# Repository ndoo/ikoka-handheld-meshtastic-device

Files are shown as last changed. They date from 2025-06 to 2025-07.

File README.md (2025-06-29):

# Ikoka Stick Meshtastic Device

## Ikoka! (行こか!)

“行こか?” or “行こか!” is [Kansai dialect](https://en.wikipedia.org/wiki/Kansai_dialect) for “shall we go?” or “let’s go!”.

I hope that building these long-range Meshtastic designs inspires you to go on your next [DXing](https://en.wikipedia.org/wiki/DXing) adventure.

## Features

- LoRa
  - Up to 33 dBm (2 W) output power
  - 410–493 MHz (433 MHz band) or 850–930 MHz (868/915/923 MHz band)
- Bluetooth 5 LE
- Lithium-ion battery with charging
- 0.96" OLED display

Feature set above depends on part selection.

### Hardware

### Parts Selection

Several options are available depending on the feature set you need.

#### Microcontroller

- [Seeed Studio XIAO-nRF52840](https://www.seeedstudio.com/Seeed-XIAO-BLE-nRF52840-p-5201.html) - Bluetooth 5/LE
- [Seeed Studio XIAO-ESP32-S3](https://www.seeedstudio.com/XIAO-ESP32S3-p-5627.html) - Bluetooth 5/LE and Wi-Fi 4 (2.4 GHz)

#### LoRa Module

- [E22-400M22S](https://www.cdebyte.com/products/E22-400M22S) (410–493 MHz at 22 dBm)
- [E22-400M30S](https://www.cdebyte.com/products/E22-400M30S) (410–493 MHz at 30 dBm)
- [E22-400M33S](https://www.cdebyte.com/products/E22-400M33S) (410–493 MHz at 33 dBm)
- [E22-900M22S](https://www.cdebyte.com/products/E22-900M22S) (850–930 MHz at 22 dBm)
- [E22-900M30S](https://www.cdebyte.com/products/E22-900M30S) (850–930 MHz at 30 dBm)
- [E22-900M33S](https://www.cdebyte.com/products/E22-900M33S) (850–930 MHz at 33 dBm)

#### Lithium-ion Battery (4.2V charging termination, optional)

- Lithium-polymer pouch battery cell (4.2V charge termination; connector: Molex PicoBlade 1x02P, pitch 1.25mm)

#### OLED Display (Optional)

- Generic SSD1306 0.96" OLED display modules with FPC connector ([Vishay OLED-128O064D-BPP3N00000](https://www.vishay.com/en/product/37902/) or generic OLEDs with the same connector dimensions and pinout)

## Firmware

### GPIO Assignment

| XIAO Pin | Function | XIAO-nRF52840 | XIAO-ESP32-S3 |
|---|---|---|---|
| 1 (D0) | User button | 2 (P0.02) | 1 |
| 2 (D1) | EBYTE E22 - DIO1 | 3 (P0.03) | 2 |
| 3 (D2) | EBYTE E22 - RST | 28 (P0.28) | 3 |
| 4 (D3) | EBYTE E22 - BUSY | 29 (P0.29) | 4 |
| 5 (D4) | EBYTE E22 - SPI NSS | 4 (P0.04) | 5 |
| 6 (D5) | EBYTE E22 - RXEN | 5 (P0.05) | 6 |
| 7 (D6) | SSD1306 OLED - I2C SDA | 43 (P1.11) | 43 |
| 8 (D7) | SSD1306 OLED - I2C SCL | 44 (P1.12) | 44 |
| 9 (D8) | EBYTE E22 - SPI SCK | 45 (P1.13) | 7 |
| 10 (D9) | EBYTE E22 - SPI MISO | 46 (P1.14) | 8 |
| 11 (D10) | EBYTE E22 - SPI MOSI | 47 (P1.15) | 9 |
| 12 | SSD1306 OLED - 3.3V | 3V3 | 3V3 |
| 13 | GND | GND | GND |
| 14 | NC | 5

#### XIAO-nRF52840

- EBYTE E22 LoRa
  - LoRa pins are identical to the officially-supported [Seeed Xiao NRF52840 Kit](https://www.seeedstudio.com/XIAO-nRF52840-Wio-SX1262-Kit-for-Meshtastic-p-6400.html) on [Meshtastic Web Flasher](https://flasher.meshtastic.org/)
  - LoRa will work out of the box on officially-supported firmware
  - Special consideration must be taken if using the E22-900M33S module
    - Set the transmit power to ≤ 9 dBm on first use (when setting the LoRa region)
    - **Transmit power must never be set greater than 9 dBm*- to avoid damaging the module's RF frontend
- SSD1306 OLED I2C
  - Pin D6/P1.11 and D7/P1.12 are [reserved for the L76K GPS module in the officially-supported variant](https://github.com/meshtastic/firmware/blob/152b8b1b0235bc461c6e4451fbcdac0987b8bf90/variants/seeed_xiao_nrf52840_kit/variant.h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)
  - A custom firmware must be built to define these pins as I2C (TODO)
- User button
  - Pin D0/P0.02 is [reserved for the L76K GPS module in the officially supported variant](https://github.com/meshtastic/firmware/blob/152b8b1b0235bc461c6e4451fbcdac0987b8bf90/variants/seeed_xiao_nrf52840_kit/variant.h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)
  - A custom firmware must be built to define this pin as the user button (TODO)

## PCB Renders

### PCB Top

top

### PCB Bottom

bottom

### Rotating GIF

animation

(Rendered with [kicad-render](https://github.com/linalinn/kicad-render).)

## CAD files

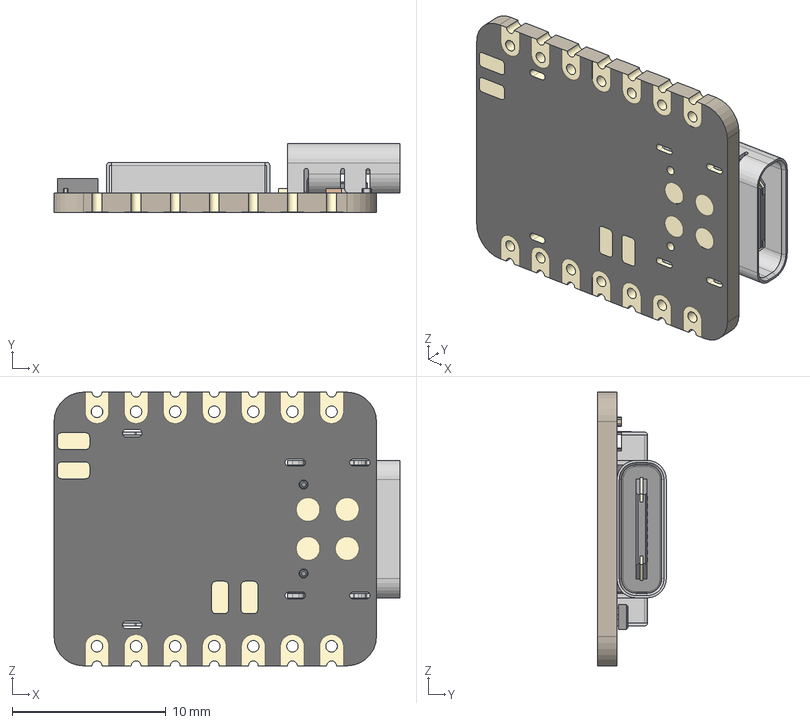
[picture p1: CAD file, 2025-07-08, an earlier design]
3dmodels/XIAO-nRF52840 v15.step
22.5 x 4.46 x 17.8 mm
BOSS-EXTRUDE14_8_
BOSS-EXTRUDE7_4_
BOSS-EXTRUDE7_3_
BOSS-EXTRUDE14_4_
BOSS-EXTRUDE14_2_
BOSS-EXTRUDE14_11_
BOSS-EXTRUDE7_7_
BOSS-EXTRUDE14_9_
BOSS-EXTRUDE14_3_
BOSS-EXTRUDE14_7_
MIRROR2
BOSS-EXTRUDE14_5_
BOSS-EXTRUDE14_12_
BOSS-EXTRUDE7_8_
BOSS-EXTRUDE7_1_
BOSS-EXTRUDE14_10_
BOSS-EXTRUDE7_9_
BOSS-EXTRUDE14_6_
BOSS-EXTRUDE14_1_
BOSS-EXTRUDE7_6_
BOSS-EXTRUDE7_2_
CUT-EXTRUDE5
BOSS-EXTRUDE7_5_
Shield
Pins
CAP x 2
ANT1
Silkscreen
CAP 3
LED
USR
2 v1

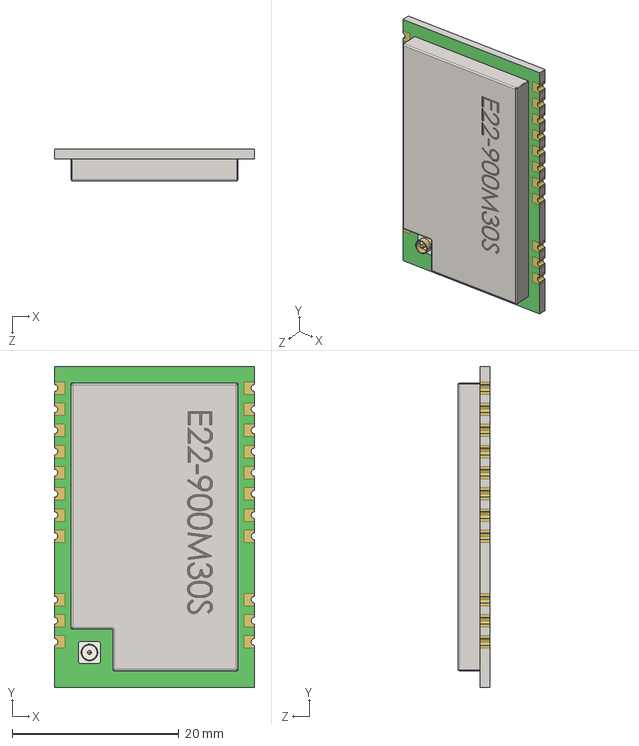
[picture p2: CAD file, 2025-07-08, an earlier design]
3dmodels/E22-900M30S.STEP
24.0 x 38.5 x 3.88 mm

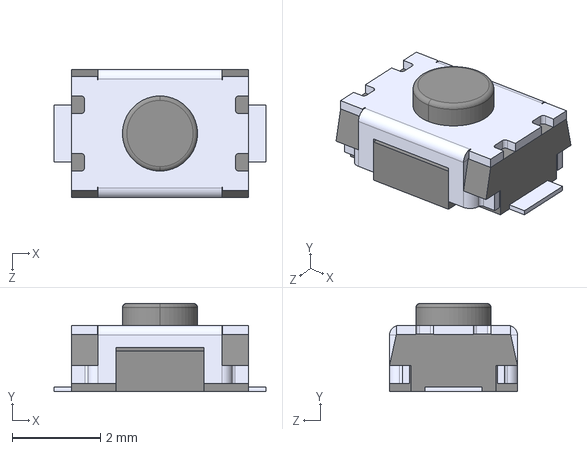
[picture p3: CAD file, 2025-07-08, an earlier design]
3dmodels/TS-1088-AR02016--3DModel-STEP-269445.STEP
4.80 x 2.00 x 2.90 mm

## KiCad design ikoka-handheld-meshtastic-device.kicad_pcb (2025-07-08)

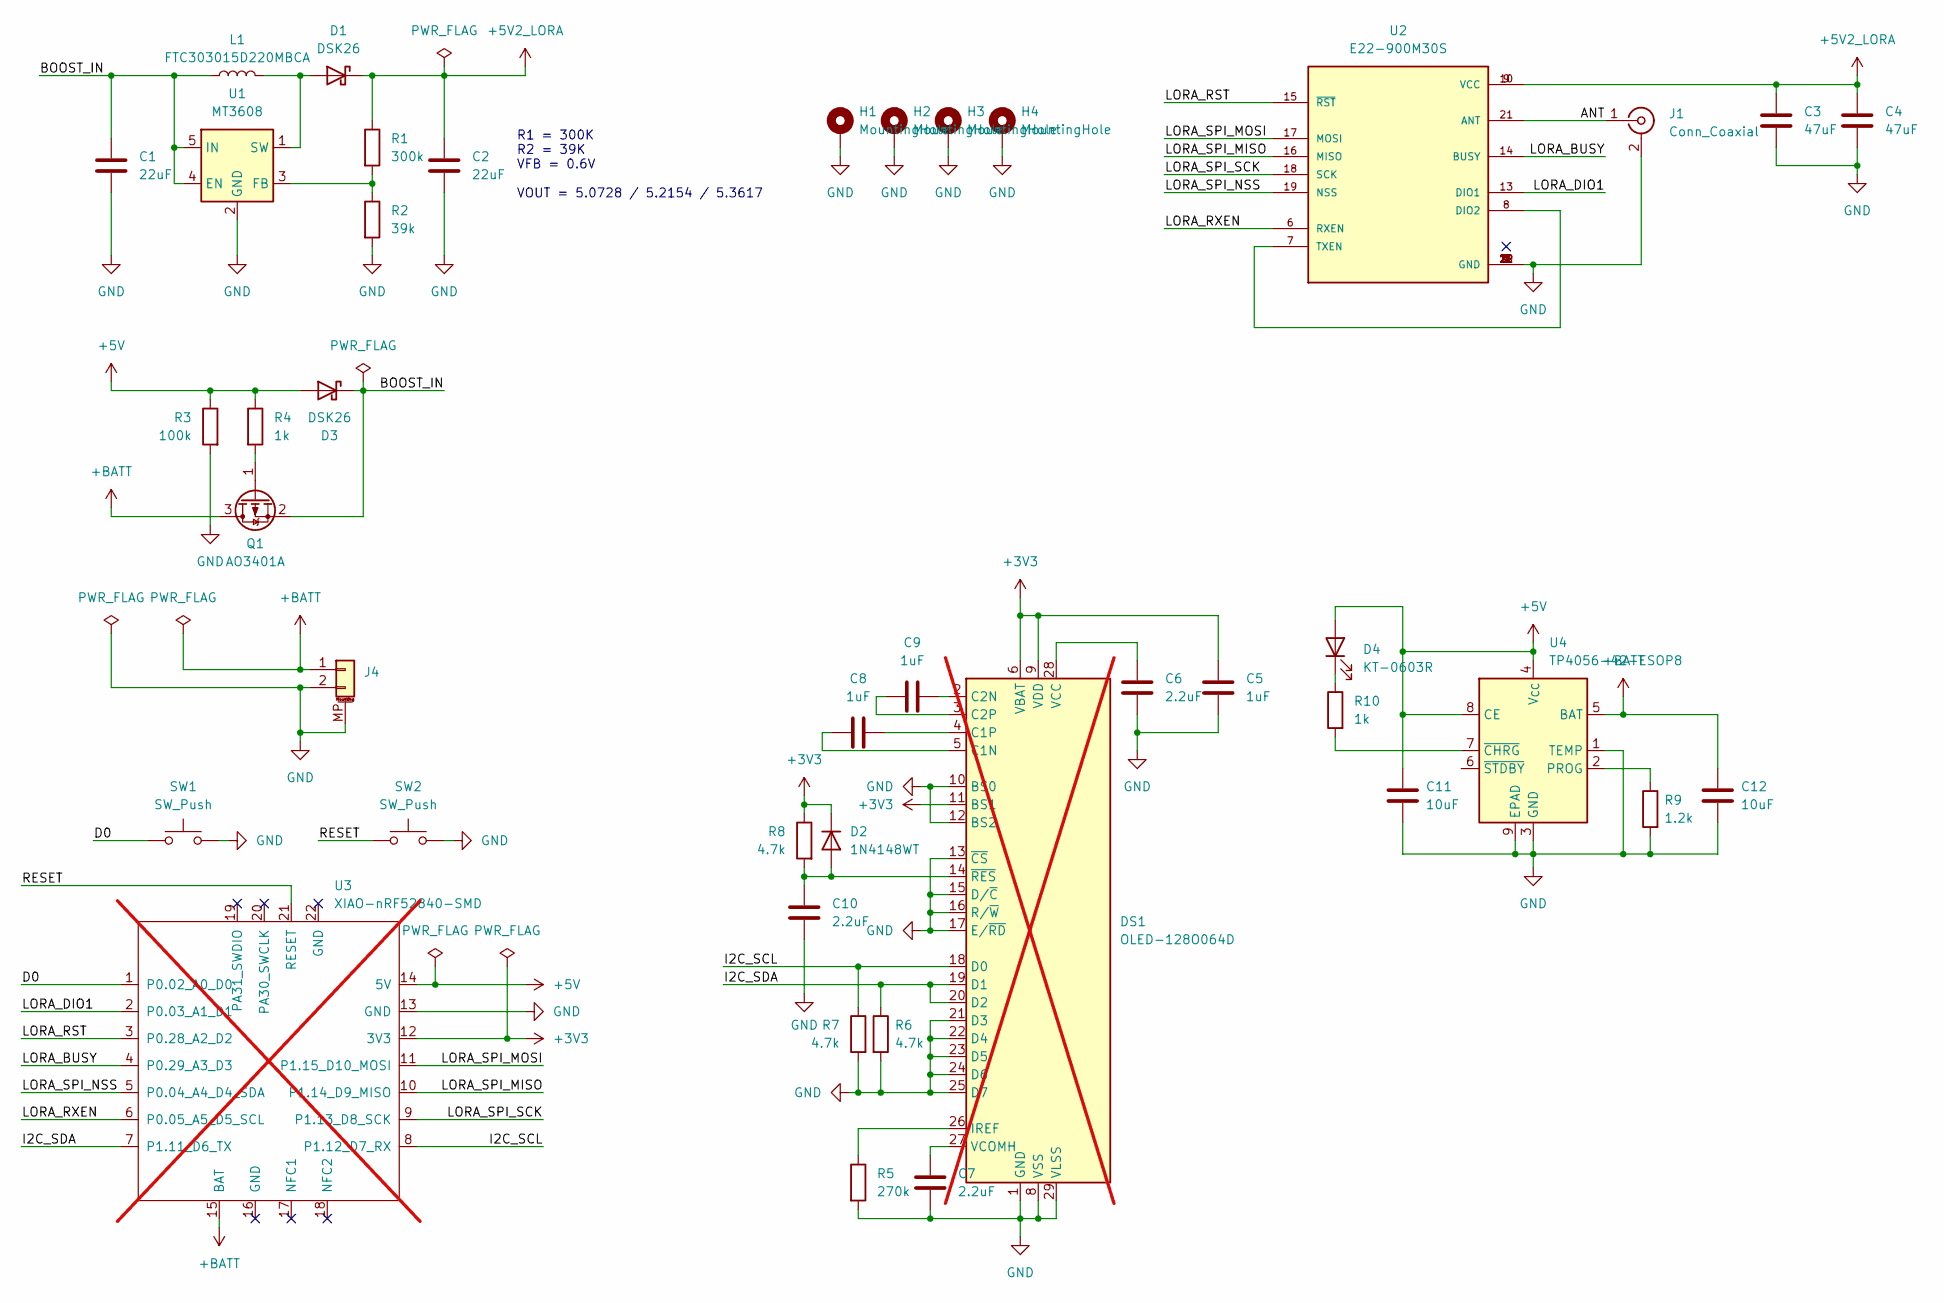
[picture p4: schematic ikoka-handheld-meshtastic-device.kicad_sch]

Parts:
C1, C2: 22uF; C_0603_1608Metric; LCSC C59461
C3, C4: 47uF; C_0805_2012Metric; LCSC C16780
C5, C8, C9: 1uF; C_0603_1608Metric; LCSC C59461
C6, C7, C10: 2.2uF; C_0603_1608Metric; LCSC C59461
C11, C12: 10uF; C_0603_1608Metric; LCSC C59461
D1, D3: DSK26; D_SOD-123F; LCSC C8678
D2: 1N4148WT; D_SOD-523
D4: KT-0603R; LED_0603_1608Metric
DS1: OLED-128O064D; not fitted
H1, H2, H3, H4: MountingHole; MountingHole_2.2mm_M2_Pad_Via
J1: Conn_Coaxial; SMA_Samtec_SMA-J-P-H-ST-EM1_EdgeMount; LCSC C5250058
J4: 1.25-2PWB; Molex_PicoBlade_53261-0271_1x02-1MP_P1.25mm_Horizontal; LCSC C2905009
L1: FTC303015D220MBCA; L_Wuerth_MAPI-3015; LCSC C18724424
Q1: AO3401A; SOT-23
R1: 300k; R_0603_1608Metric; LCSC C23024
R2: 39k; R_0603_1608Metric; LCSC C23153
R3: 100k; R_0603_1608Metric; LCSC C23024
R4, R10: 1k; R_0603_1608Metric; LCSC C23024
R5: 270k; R_0603_1608Metric; LCSC C23024
R6, R7, R8: 4.7k; R_0603_1608Metric; LCSC C23024
R9: 1.2k; R_0603_1608Metric; LCSC C23024
SW1, SW2: SW_Push; TS-1088-AR02016; LCSC C318884
U1: MT3608; SOT-23-6; LCSC C2932326
U2: E22-900M30S; XCVR_E22-900M30S; PARTREV 1.2; LCSC C411294
U3: XIAO-nRF52840-SMD; LCSC C9900124959; not fitted
U4: TP4056-42-ESOP8; SOIC-8-1EP_3.9x4.9mm_P1.27mm_EP2.41x3.3mm_ThermalVias

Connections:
+3V3: C5.1, D2.1 (K), DS1.6 (VBAT), DS1.9 (VDD), DS1.11 (BS1), R8.1, U3.12 (3V3)
+5V: C11.1, D3.2 (A), D4.2 (A), R3.1, R4.1, U3.14 (5V), U4.4 (V_{CC}), U4.8 (CE)
+5V2_LORA: C2.1, C3.1, C4.1, D1.1 (K), R1.1, U2.9 (VCC), U2.10 (VCC)
+BATT: C12.1, J4.1, Q1.3 (D), U3.15 (BAT), U4.5 (BAT)
/ANT: J1.1 (In), U2.21 (ANT)
/BOOST_IN: C1.1, D3.1 (K), L1.1, Q1.2 (S), U1.4 (EN), U1.5 (IN)
/D0: SW1.1, U3.1 (P0.02_A0_D0)
/I2C_SCL: DS1.18 (D0), R7.1, U3.8 (P1.12_D7_RX)
/I2C_SDA: DS1.19 (D1), DS1.20 (D2), R6.1, U3.7 (P1.11_D6_TX)
/LORA_BUSY: U2.14 (BUSY), U3.4 (P0.29_A3_D3)
/LORA_DIO1: U2.13 (DIO1), U3.2 (P0.03_A1_D1)
/LORA_RST: U2.15 (~RST), U3.3 (P0.28_A2_D2)
/LORA_RXEN: U2.6 (RXEN), U3.6 (P0.05_A5_D5_SCL)
/LORA_SPI_MISO: U2.16 (MISO), U3.10 (P1.14_D9_MISO)
/LORA_SPI_MOSI: U2.17 (MOSI), U3.11 (P1.15_D10_MOSI)
/LORA_SPI_NSS: U2.19 (NSS), U3.5 (P0.04_A4_D4_SDA)
/LORA_SPI_SCK: U2.18 (SCK), U3.9 (P1.13_D8_SCK)
/RESET: SW2.1, U3.21 (RESET)
GND: C1.2, C2.2, C3.2, C4.2, C5.2, C6.2, C7.2, C10.2, C11.2, C12.2, DS1.1 (GND), DS1.8 (VSS), DS1.10 (BS0), DS1.12 (BS2), DS1.13 (~CS), DS1.15 (D/~C), DS1.16 (R/~W), DS1.17 (E/~RD), DS1.21 (D3), DS1.22 (D4), DS1.23 (D5), DS1.24 (D6), DS1.25 (D7), DS1.29 (VLSS), DS1.30 (GND), H1.1, H2.1, H3.1, H4.1, J1.2 (Ext), J4.2, J4.MP (MountPin), R2.2, R3.2, R5.2, R6.2, R7.2, R9.2, SW1.2, SW2.2, U1.2 (GND), U2.1 (GND), U2.2 (GND), U2.3 (GND), U2.4 (GND), U2.5 (GND), U2.11 (GND), U2.12 (GND), U2.20 (GND), U2.22 (GND), U3.13 (GND), U4.1 (TEMP), U4.3 (GND), U4.9 (EPAD)
unnamed: D1.2 (A), L1.2, U1.1 (SW)
unnamed: C10.1, D2.2 (A), DS1.14 (~RES), R8.2
unnamed: D4.1 (K), R10.1
unnamed: C8.1, DS1.5 (C1N)
unnamed: C8.2, DS1.4 (C1P)
unnamed: C9.2, DS1.2 (C2N)
unnamed: C9.1, DS1.3 (C2P)
unnamed: DS1.26 (IREF), R5.1
unnamed: C6.1, DS1.28 (VCC)
unnamed: C7.1, DS1.27 (VCOMH)
unnamed: Q1.1 (G), R4.2
unnamed: R1.2, R2.1, U1.3 (FB)
unnamed: U2.7 (TXEN), U2.8 (DIO2)
unnamed: R9.1, U4.2 (PROG)
unnamed: R10.2, U4.7 (~CHRG)

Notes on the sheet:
R1 = 300K R2 = 39K VFB = 0.6V VOUT = 5.0728 / 5.2154 / 5.3617

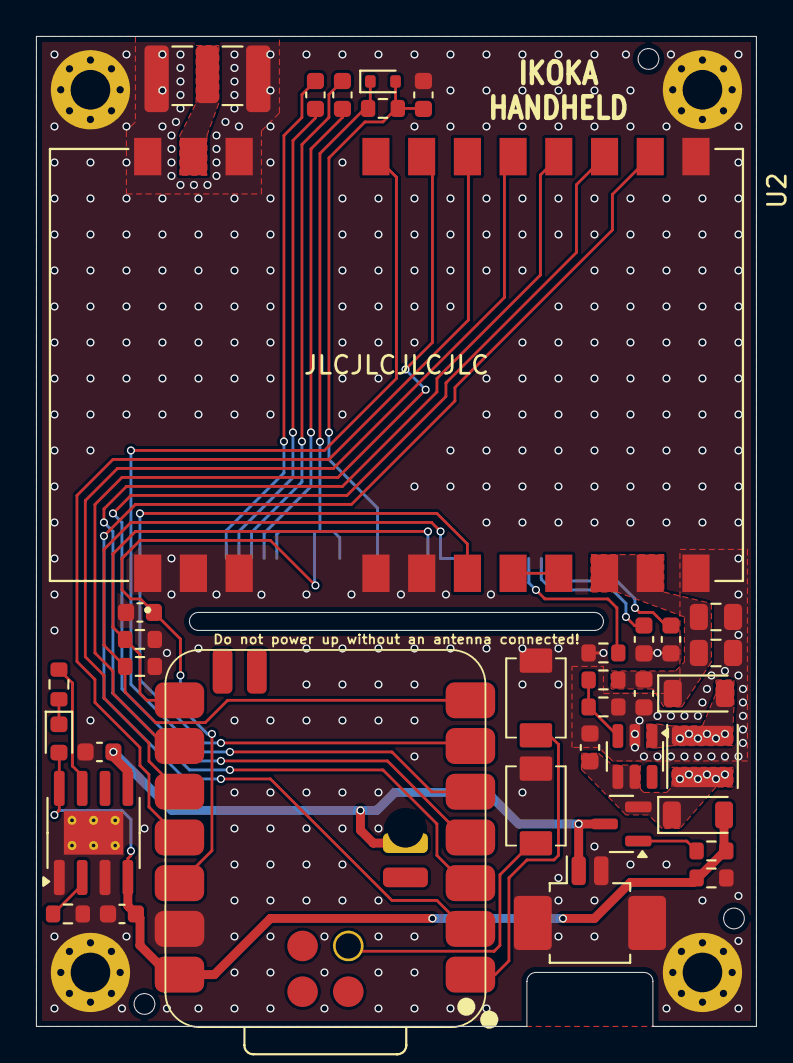
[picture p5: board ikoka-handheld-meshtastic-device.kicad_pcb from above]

Board: 2 copper layers, 40.0 x 55.0 mm, 41 parts (1 on the bottom side), 34 nets.

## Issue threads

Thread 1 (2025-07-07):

OLED connector is mirrored

ndoo, 2025-07-07:
OLED connector footprint was designed for the OLED to fold back on the same side of the PCB, we are using it on the opposing side so the pinout is reversed.

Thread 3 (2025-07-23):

OLED does not work and Meshtastic boot hangs on I2C bus access

ndoo, 2025-07-23:
OLED does not work due to I2C_SDA and I2C_SCL having incorrect 4.7kΩ pull-down to ground instead of pull-up to 3V3.

Hardware workaround at current version: Do not populate R6 and R7.

Closed 2025-07-23.

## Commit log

2025-06-29 BREAKING CHANGE: Redesign as Ikoka Handheld
    [E22-900M30S.STEP, TS-1088-AR02016--3DModel-STEP-269445.STEP, TS-1187A.step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]
2025-06-29 fix: Add BAT output capacitor on TP4056
    [ikoka-handheld-meshtastic-device.kicad_pcb, ikoka-handheld-meshtastic-device.kicad_sch]
2025-07-08 fix: Flip SSD1306 footprint (fixes #1)
    [ikoka-handheld-meshtastic-device.kicad_pcb, ikoka-handheld-meshtastic-device.kicad_sch]
2025-07-08 fix(pcbnew): Add user drawings for dimensions and fix hole alignment
    [ikoka-handheld-meshtastic-device.kicad_pcb]
2025-07-08 feat: Change TP4056 charge current from 1A to 780mA
    For a total of 880mA (780mA TP4056 + 100mA onboard XIAO charger).
    Most pouch cells the size of the PCB are around 1000mAh, and 1.1A charge rate is above 1C for these cells, which will increase battery wear.
    [ikoka-handheld-meshtastic-device.kicad_pcb, ikoka-handheld-meshtastic-device.kicad_sch]
2025-07-15 chore: Use fork of OPL_Kicad_Library with Handsoldering footprint
2025-07-15 fix: Change inductor from 22uH to 2.2uH, Move XIAO up 0.1mm
    - Change inductor from 22uH to 2.2uH
    - From: FTC303015D220MBCA
    - To: FNR3015S2R2MT
    - Lower DCR
    - Higher current headroom
    - Better transient response
    - Move XIAO module up 0.1mm for better PCB edge clearance
    [ikoka-handheld-meshtastic-device.kicad_pcb, ikoka-handheld-meshtastic-device.kicad_sch]
2025-07-15 chore: Clear ERC and DRC errors/warnings
    [ikoka-handheld-meshtastic-device.kicad_pcb, ikoka-handheld-meshtastic-device.kicad_sch]
2025-07-15 fix(pcbnew): XIAO 3dmodel and footprint type again...
    [ikoka-handheld-meshtastic-device.kicad_pcb]
2025-07-15 feat(pcbnew): 3dmodel for TP4056
    [ikoka-handheld-meshtastic-device.kicad_pcb]
2025-07-15 chore: Update JLCPCB parts selection based on preceding changes
    [ikoka-handheld-meshtastic-device.kicad_pcb, ikoka-handheld-meshtastic-device.kicad_sch]
2025-07-15 feat(eeschema): Change MT3608 to MT3608B (newer part)
    [ikoka-handheld-meshtastic-device.kicad_pcb, ikoka-handheld-meshtastic-device.kicad_sch]
2025-07-15 chore(pcbnew): Move JLCJLCJLCJLC silk away from vias
    [ikoka-handheld-meshtastic-device.kicad_pcb]
2025-07-15 fix: OLED did not need to be mirrored, add pin 1 & 30 silk
    [ikoka-handheld-meshtastic-device.kicad_pcb, ikoka-handheld-meshtastic-device.kicad_sch]
2025-07-15 feat: Use more 1.5k and 300k resistors where possible to simplify BoM
    [ikoka-handheld-meshtastic-device.kicad_pcb, ikoka-handheld-meshtastic-device.kicad_sch]
2025-07-15 feat(pcbnew): Improve layout
    - All SX1262 traces to the back
    - Don't run SSD1306 charge pump and SX1262 traces on top of each other in parallel
    - Move SSD1306 reset circuit to bottom half of PCB
    [ikoka-handheld-meshtastic-device.kicad_pcb]
2025-07-15 feat: OSHW logo
    [ikoka-handheld-meshtastic-device.kicad_pcb, ikoka-handheld-meshtastic-device.kicad_sch]
2025-07-15 fix: MT3608B wrongly selected as MT3608L in JLCPCB DB
    [ikoka-handheld-meshtastic-device.kicad_pcb]
2025-07-15 fixup! fix: Change inductor from 22uH to 2.2uH, Move XIAO up 0.1mm
    [ikoka-handheld-meshtastic-device.kicad_pcb, ikoka-handheld-meshtastic-device.kicad_sch]
2025-07-21 Update XIAO nRF52840 footprint
2025-07-21 feat: Boost converter improvements
    - Change Schottky diode from DSK26 (Vf 0.7V, Iav 2A) to DSK34 (Vf 0.55V, Iav 3A)
    - Change inductor from FNR3015S2R2MT (2.2µH, 2A/2A, DCR 0.06Ω) to FTC303018D4R7MBCA (4.7µH, 4.2A/3A, DCR 0.087Ω)
    [ikoka-handheld-meshtastic-device.kicad_pcb, ikoka-handheld-meshtastic-device.kicad_sch]
2025-07-23 fix: Remove I2C 4.7kΩ pull-down resistors - The resistors are wrongly wired as pull-down to GND instead of pull-up to 3V3, I2C is open drain and requires pull-up - Remove them entirely and rely on nr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
    Fixes #3.
    [ikoka-handheld-meshtastic-device.kicad_pcb, ikoka-handheld-meshtastic-device.kicad_sch]
2025-07-24 fix: Add 4.7kΩ pull-up resistors on I2C bus (fixes #5)
    [ikoka-handheld-meshtastic-device.kicad_pcb, ikoka-handheld-meshtastic-device.kicad_sch]
